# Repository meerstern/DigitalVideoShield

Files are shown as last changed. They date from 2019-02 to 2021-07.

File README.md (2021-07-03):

# DigitalVideoShield
Digital Video Shield for Arduino. The shield enables Arduino to connect HDMI/DVI displays.

## 概要 
  * SPIからDVI映像出力(HDMIコネクタ)を行うArduinoシールドです。  
  * FTDI製ビデオエンジンBT816とDVIトランスミッタTFP410/SiI164を搭載しています。
  
## 特徴 
  * Arduinoから任意の文字列や図形、画像をDVI/HDMIディスプレイに描画することができます。  
  * 1MBのバッファRAMを搭載しているため、滑らかに表示の切り替えが可能です。
  * バッファIC搭載のSPI通信ポートは5V耐圧のため、ArduinoUNOにも対応しています。  
  * 電源はArduinoピンから5Vおよび3.3Vを使用します。  
  * 最大解像度は800x600です。  
  * PCLK最大60MHz、24bitフルカラー(RGB888)に対応しています。  
  * 128MbitのNOR Flash W25Q128を搭載しており、フォントや画像といった任意のデータを保存可能です。  
  * microSDスロットを搭載しています。  
  * BT816のGPIOやタッチパネルポート等のIOは基板上のテストポイントからアクセス可能です。  

## ピン配列

| Port | Arduino | 
|:---|:---|
| BT816 CS | D7pin |
| BT816 SCK | D13pin |
| BT816 MOSI  | D11pin |
| BT816 MISO | D12pin |
| BT816 PD  | D3pin |
| BT816 INT | D4pin |
| microSD CS | D5pin |
| microSD SCK | D13pin |※BT816と共通
| microSD MOSI | D11pin |※BT816と共通
| microSD MISO | D12pin |※BT816と共通

※SPIはmicroSDとBT816で共通  
※上記の信号ポートは5V耐圧  

## 表示例
　サンプルデモコード(ビデオエンジンBT816の内蔵アニメーション)を800x480のディスプレイに表示した例  
 
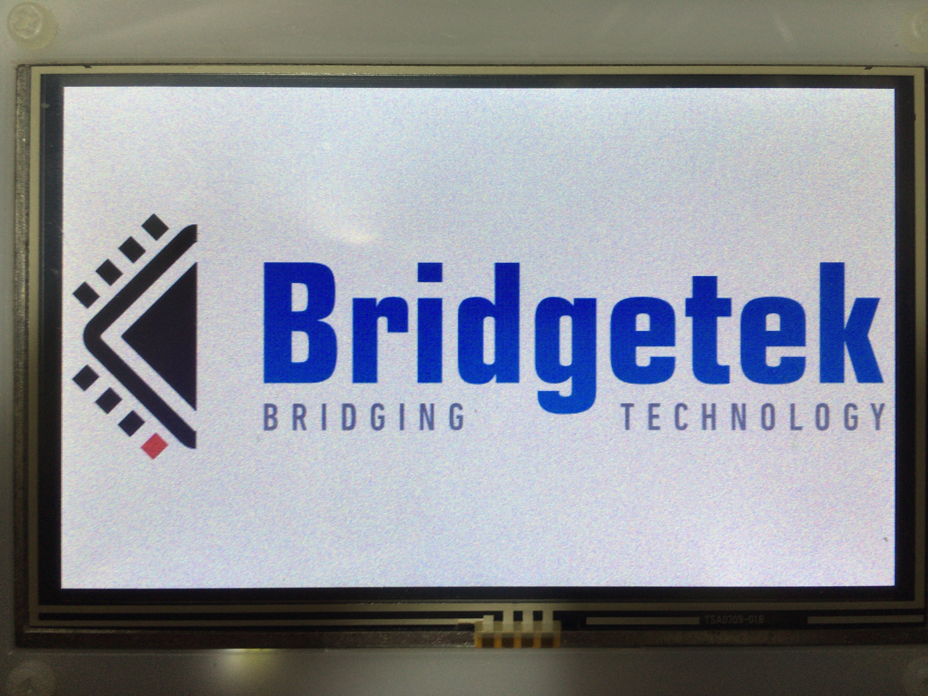
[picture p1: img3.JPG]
 

　サンプルデモコード(ビデオエンジンBT816の内蔵アニメーション)を800x480出力でHDディスプレイに表示した例  
 
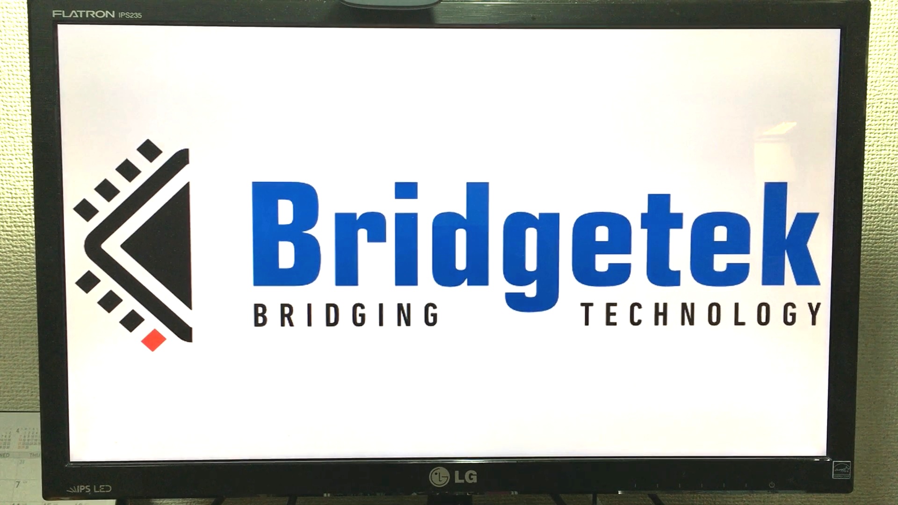
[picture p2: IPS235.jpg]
 
 
 Co-Processorエンジンによる内蔵Widgetsを800x480のディスプレイに表示した例  
 
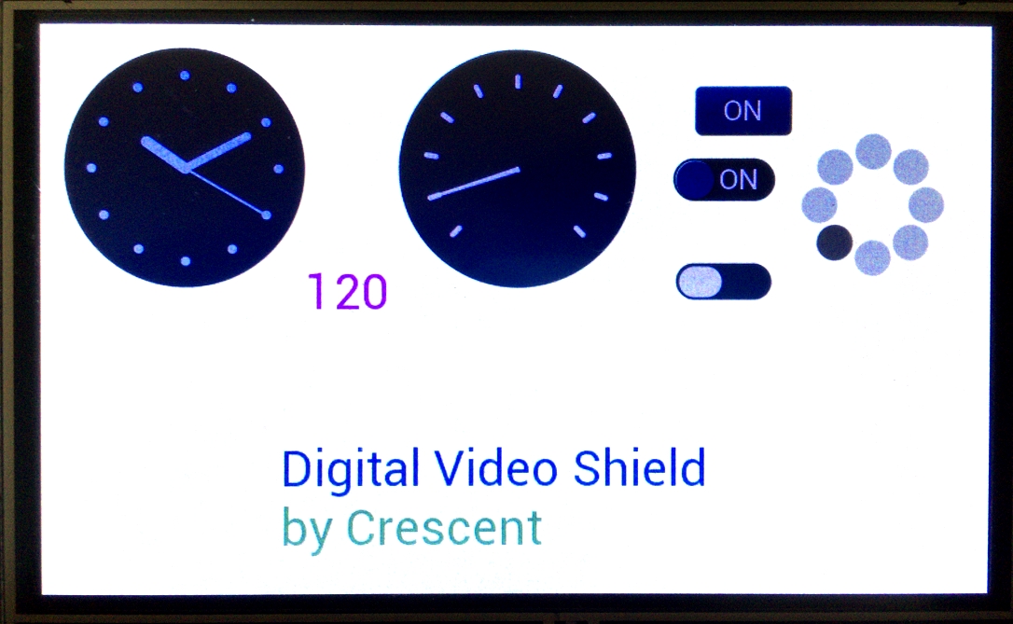
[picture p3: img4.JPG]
 
 ※内蔵Widgetsはテキスト、ボタン、時計、プログレスバー、スライダー、トグルボタンなどが内蔵されています。  
   
   数行のコードの記述で任意の表示をすることができます。     
   ボタン、スライダー等の入力イベントを使用する場合は別途、抵抗膜方式のパネルと配線が必要です。  
   
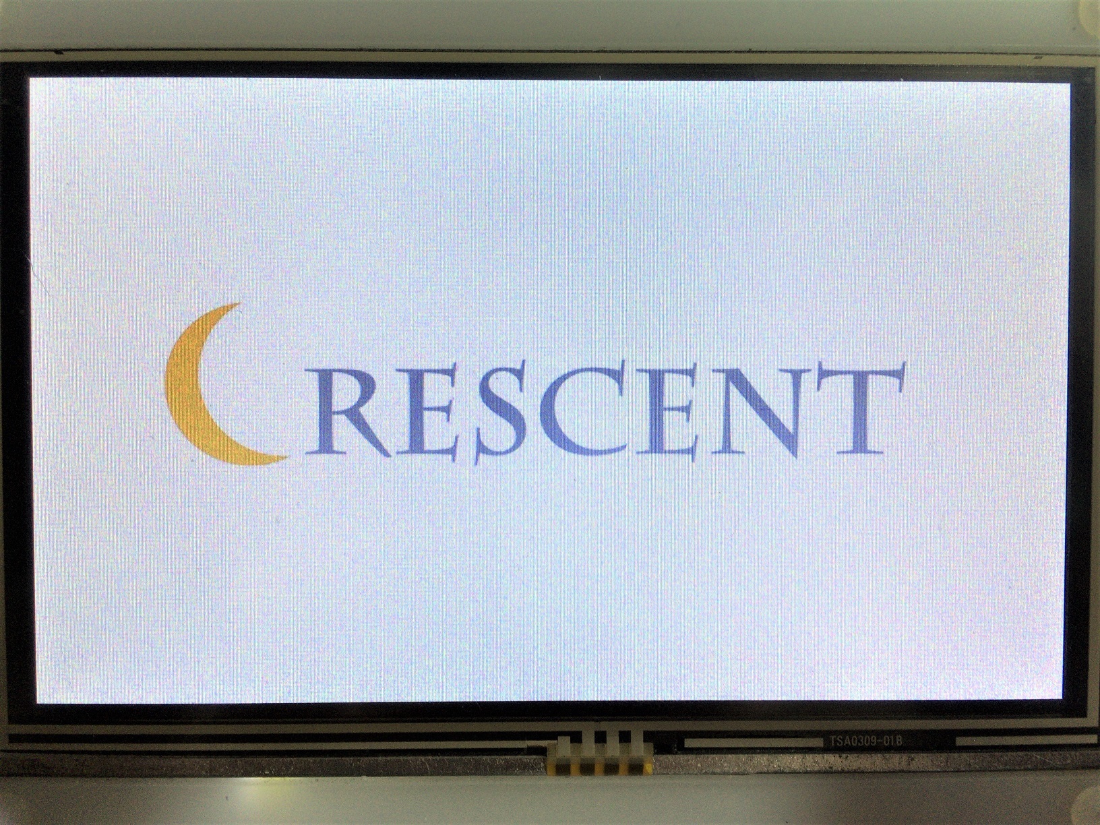
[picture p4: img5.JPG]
 
 ※SDカードから800x480ピクセルサイズのJPG/PNGをBT816のRAMに読み込ませて800x480のディスプレイに表示した例  

## 注意点
  * Arduinoピンヘッダは別売です。    
  * 映像出力コネクタはHDMIコネクタですが、出力はDVI出力となります。  
  * HDCP機能、HDMIコネクタを介した音声出力、ハイビジョン出力には対応していません。  
  * 全てのHDMI/DVI端子を有するディスプレイでの表示は保証できません。  
  * パソコン用ディスプレイのHDMIコネクタから表示できる場合がありますが、テレビやテレビ用ディスプレイはハイビジョン専用のため、表示できません。   
  * パソコン用ディスプレイの場合は低解像度入力で自動的に拡大表示されますが、ディスプレイによって正しく表示されない場合があります。  
  
機能詳細については[BT816][1]を参照ください。  

## 販売サイト
  * [家電のケンちゃん][2]、 [スイッチサイエンス][3]で販売しております。

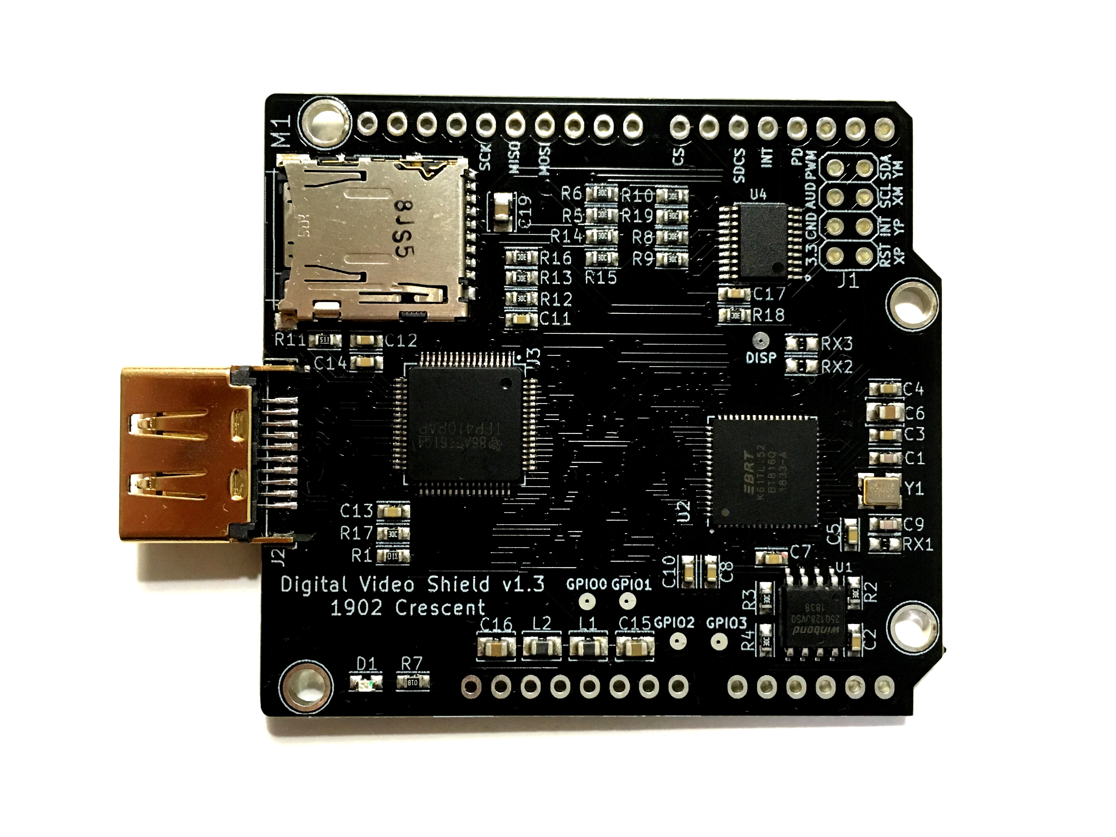
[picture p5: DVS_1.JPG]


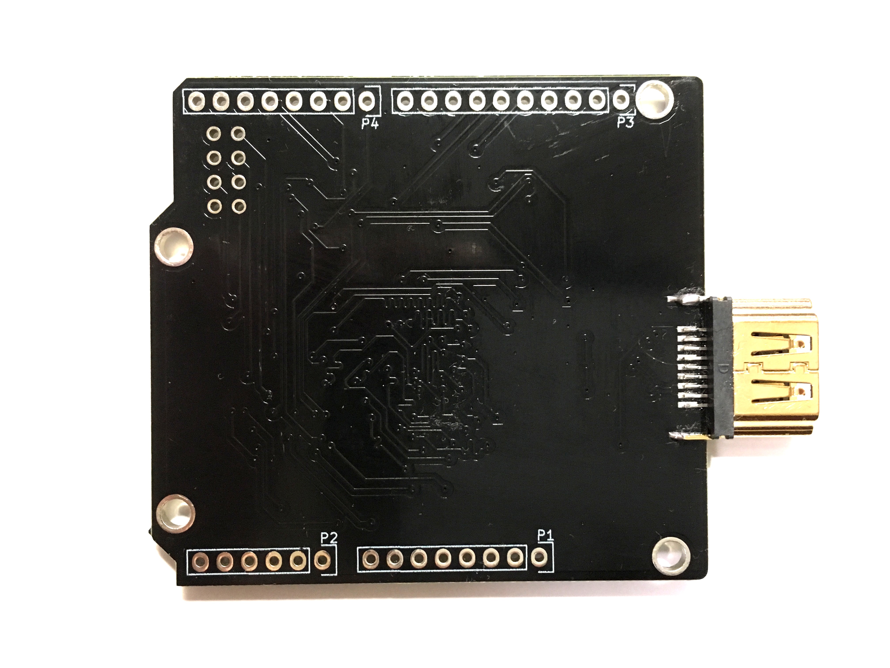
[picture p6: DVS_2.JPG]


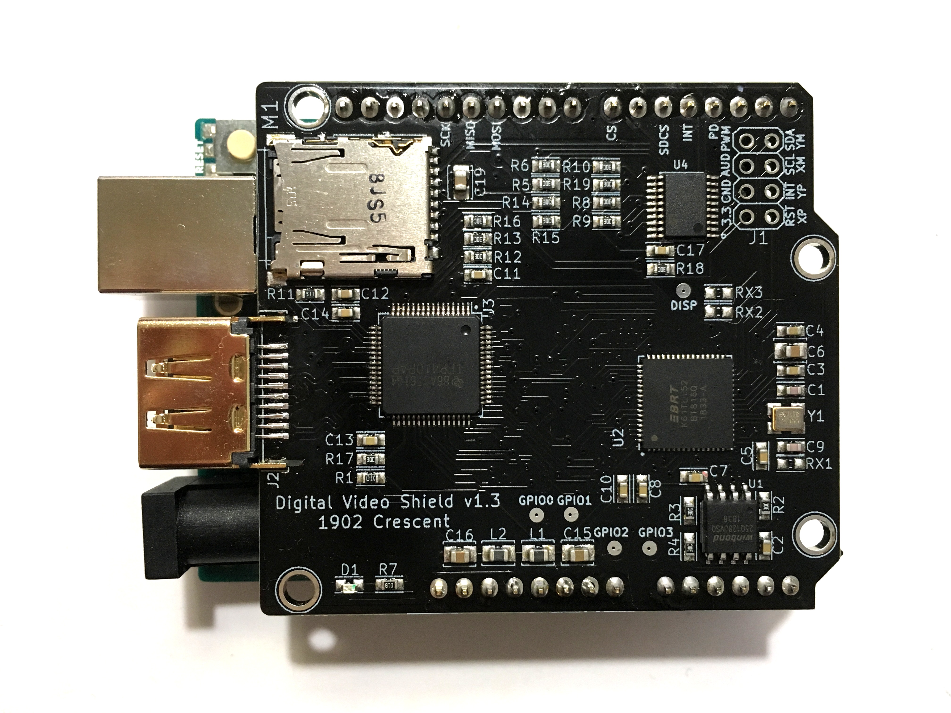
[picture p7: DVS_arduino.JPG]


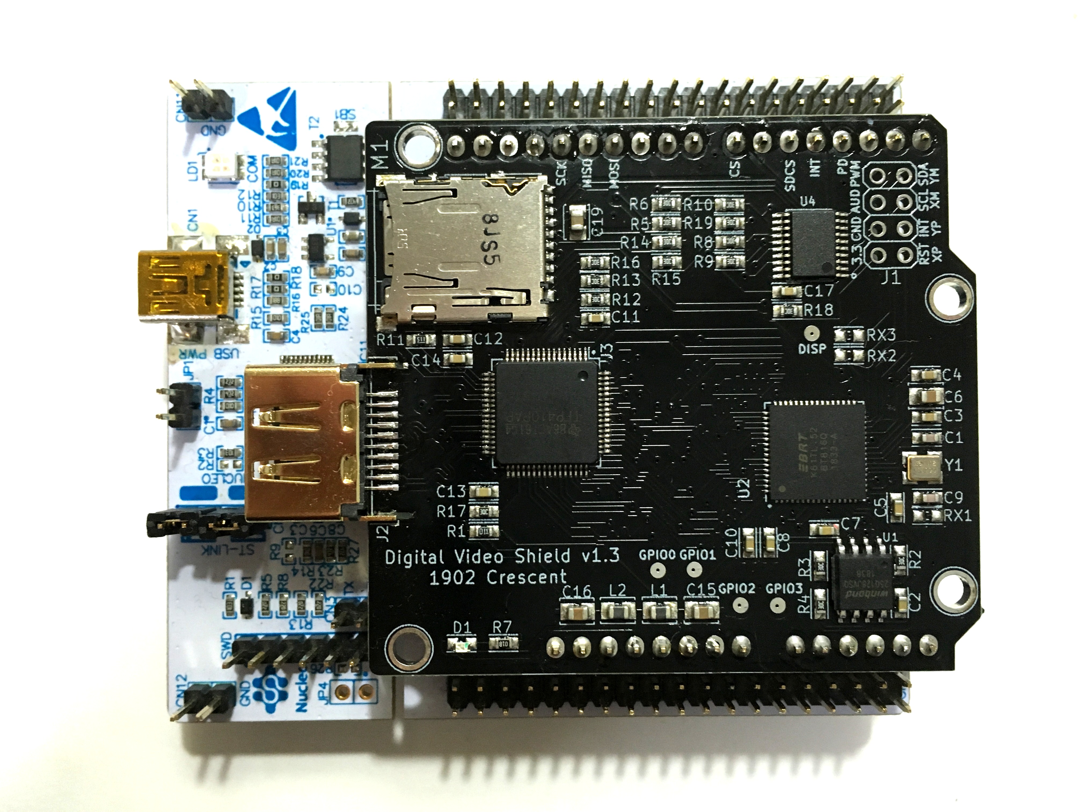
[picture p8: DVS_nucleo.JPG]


[1]: https://www.ftdichip.com/Products/ICs/BT815_6.html "*1"

[2]: https://www.kadenken.com/shopdetail/000000000884/ct150/page1/order/ "*2"

[3]: https://www.switch-science.com/catalog/5516/ "*3"

MIT Lisense

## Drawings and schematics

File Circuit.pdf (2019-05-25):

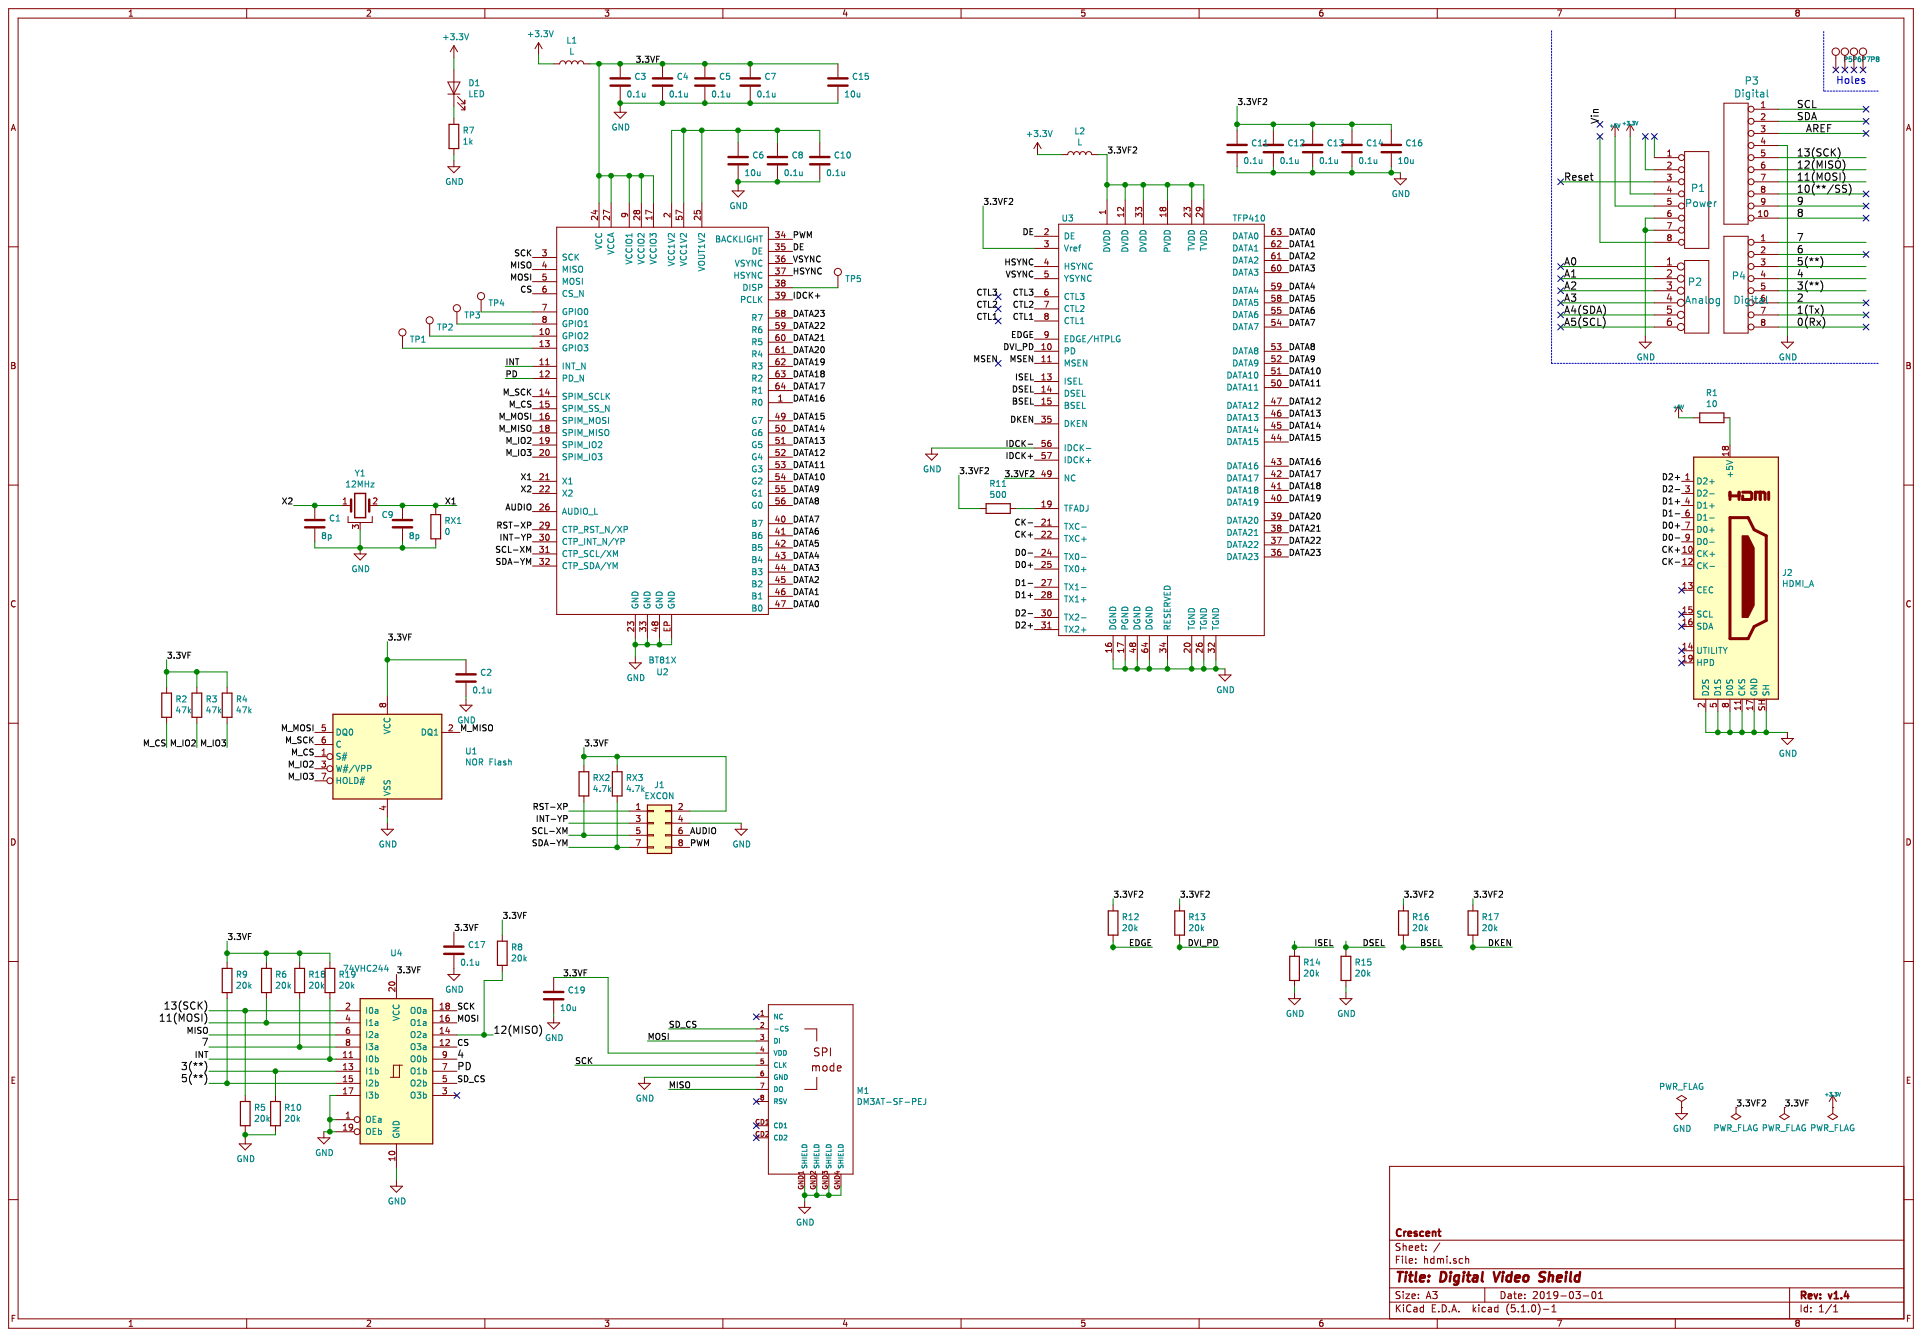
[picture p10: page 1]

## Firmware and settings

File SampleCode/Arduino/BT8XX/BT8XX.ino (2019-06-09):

/* * * * * * * * * * * * * * * * * * * * * * * * * *
 * FTDI EVE Firmware for BT81X                     *
 * Copyright (c) 2019                              *
 * K.Watanabe,Crescent                             *
 * Released under the MIT license                  *
 * http://opensource.org/licenses/mit-license.php  *
 * 19/02/16 v1.0 Initial Release                   *
 * 19/02/27 v1.1 Fix initialization stability      *
 * 19/04/28 v1.2 Add Co-Processor command          *
 * * * * * * * * * * * * * * * * * * * * * * * * * */

#include <Arduino.h>    
#include <SPI.h>       

#include "BT81X.h"

#ifdef ENABLE_SD
  #include <SD.h>
   File sdfile;
#endif

FILE serial_stdout;

void setup() 
{
    unsigned int cnt;
	
    Serial.begin(9600);
    fdev_setup_stream(&serial_stdout, serial_putchar, NULL, _FDEV_SETUP_WRITE);
    stdout = &serial_stdout;
             
    SPI.begin();          					// Initialize SPI
	  Serial.println("Initialize Start!! \r\n");
    SPI.setBitOrder(MSBFIRST);      		// Send data most significant bit first
    SPI.setDataMode(SPI_MODE0);     		// Clock idle zero, clock data into BT81X on rising edge
    SPI.setClockDivider(SPI_CLOCK_DIV4);    // Set rate at 4MHz (16MHz OSC / 4)

    pinMode(irqPin, INPUT_PULLUP);   		// BT81X interrupt output (not used in this example)
    pinMode(pwrPin, OUTPUT);     			// BT81X Power Down (reset) input
    pinMode(csPin, OUTPUT);      			// BT81X SPI bus CS# input
    pinMode(sdcsPin, OUTPUT);      			// BT81X SPI bus CS# input

	
    digitalWrite(sdcsPin, HIGH);   			// Set CS# high to start - SPI inactive
	  digitalWrite(csPin, HIGH);   			// Set CS# high to start - SPI inactive
    digitalWrite(pwrPin, HIGH);    			// Set PD# high to start
    delay(80);          					// Wait a few MS before waking the BT81X
    digitalWrite(pwrPin, LOW);    			// Set PD# high to start
    delay(80);  
    digitalWrite(pwrPin, HIGH);    			// Set PD# high to start
	  delay(80); 

	
  	EveWriteCmd(CLKEXT);    
  	EveWriteCmd(CLK36M);      
   	EveWriteCmd(ACTIVE);     
  	delay(300); 

#ifdef ENABLE_SD
	if (!SD.begin(sdcsPin)) 
	{
		Serial.println("SD initialization failed!\n");
	}    
#endif
	
  	while(CHIP_ID_RESET!=EveReadData8(REG_ID)){
  		cnt++;
  		if(cnt>100){
        Serial.print("EVE NOT Found!! :");
        Serial.println(EveReadData8(REG_ID));
  			delay(100);
  			break;
  		}
  	} 
    if(cnt<100)Serial.println("EVE Found!!");

      
  
  	cnt=0;
  	while(0x0!=EveReadData16(REG_CPURESET)){
  		cnt++;
      delay(1);
  		if(cnt>100){
  			Serial.print("EVE NOT Active!! :");
  			Serial.println(EveReadData16(REG_CPURESET));
  			delay(200);
  		}
  	}
	  if(cnt<100)Serial.println("EVE Active!!");

    EveWriteData32(REG_FREQUENCY,0x3938700);   // Set CPU Frequency
    
  	// Set Resolution
  	EveWriteData16(REG_HCYCLE,	USR_HCYCLE);
  	EveWriteData16(REG_HOFFSET,	USR_HOFFSET);
  	EveWriteData16(REG_HSYNC0,	USR_HSYNC0);
  	EveWriteData16(REG_HSYNC1,	USR_HSYNC1);
  	EveWriteData16(REG_VCYCLE,	USR_VCYCLE);
  	EveWriteData16(REG_VOFFSET,	USR_VOFFSET);
  	EveWriteData16(REG_VSYNC0,	USR_VSYNC0);
  	EveWriteData16(REG_VSYNC1,	USR_VSYNC1);
  	EveWriteData8(REG_SWIZZLE,	USR_SWIZZLE);
  	EveWriteData8(REG_PCLK_POL,	USR_PCLK_POL);
  	EveWriteData16(REG_HSIZE,		USR_HSIZE);
  	EveWriteData16(REG_VSIZE,		USR_VSIZE);
  	EveWriteData8(REG_CSPREAD,	USR_CSPREAD);
  	EveWriteData8(REG_DITHER,		USR_DITHER);

    EveWriteData16(REG_GPIOX_DIR, 0xFFFF);
    EveWriteData16(REG_GPIOX, 0xFFFF);
  	
  	//Clear Dispaly
    EveWriteData32BufInc(RAM_DL,  CLEAR_COLOR_RGB(255,255,255));
    EveWriteData32BufInc(RAM_DL,  CLEAR(1,1,1));
    EveWriteData32BufInc(RAM_DL,  DISPLAY());
    EveWriteData32BufWrite();

    //Display swap
    EveWriteData8(REG_DLSWAP, DLSWAP_FRAME);


    //LCD visible
    EveWriteData8(REG_PCLK, USR_PCLK);
    delay(300);
  
    Serial.println("Hello");
}


void loop() 
{

  
//  EveDemo3();
//  while(1);  
  EveDemo();
//  //EveRecoverCoProcessor();
//  EveDemo2();  
//  EveDemo3();  
  //EveRecoverCoProcessor();
	

}


void EveWriteCmd(unsigned char ftCommand)
{
  digitalWrite(csPin, LOW);   
  SPI.transfer(ftCommand);     
  SPI.transfer(0x00);     
  SPI.transfer(0x00); 
  digitalWrite(csPin, HIGH);
}

unsigned char EveReadData8(unsigned long ftAddress)
{
  unsigned char ftData8 = ZERO;
  digitalWrite(csPin, LOW); 
  SPI.transfer((char)(ftAddress >> 16) | MEM_READ); 
  SPI.transfer((char)(ftAddress >> 8)); 
  SPI.transfer((char)(ftAddress)); 
  SPI.transfer(ZERO);      
  ftData8 = SPI.transfer(ZERO); 
  digitalWrite(csPin, HIGH); 
  return ftData8;     
}

unsigned int EveReadData16(unsigned long ftAddress)
{
  unsigned int ftData16;
  digitalWrite(csPin, LOW);
  SPI.transfer((char)(ftAddress >> 16) | MEM_READ);
  SPI.transfer((char)(ftAddress >> 8)); 
  SPI.transfer((char)(ftAddress));
  SPI.transfer(ZERO);      
  ftData16 = (SPI.transfer(ZERO));  
  ftData16 = (SPI.transfer(ZERO) << 8) | ftData16; 
  digitalWrite(csPin, HIGH);
  return ftData16;
}

unsigned long EveReadData32(unsigned long ftAddress)
{
  unsigned long ftData32;
  unsigned long res;
  digitalWrite(csPin, LOW);
  SPI.transfer((char)(ftAddress >> 16) | MEM_READ);
  SPI.transfer((char)(ftAddress >> 8));
  SPI.transfer((char)(ftAddress));
  SPI.transfer(ZERO);

  res = SPI.transfer(ZERO);
  ftData32 = ( res << 0); 
  res = SPI.transfer(ZERO);
  ftData32 = ( res << 8) | ftData32;
  res = SPI.transfer(ZERO);
  ftData32 = ( res << 16) | ftData32;
  res = SPI.transfer(ZERO);
  ftData32 = ( res << 24) | ftData32;

  digitalWrite(csPin, HIGH);
  return ftData32;
}

void EveWriteData8(unsigned long ftAddress, unsigned char ftData8)
{
  digitalWrite(csPin, LOW);
  SPI.transfer((char)(ftAddress >> 16) | MEM_WRITE);
  SPI.transfer((char)(ftAddress >> 8));
  SPI.transfer((char)(ftAddress));
  SPI.transfer(ftData8);  
  digitalWrite(csPin, HIGH);
}

void EveWriteData16(unsigned long ftAddress, unsigned int ftData16)
{

  digitalWrite(csPin, LOW);
  SPI.transfer((char)(ftAddress >> 16) | MEM_WRITE);
  SPI.transfer((char)(ftAddress >> 8));
  SPI.transfer((char)(ftAddress));
  SPI.transfer((char)(ftData16));
  SPI.transfer((char)(ftData16 >> 8));
  digitalWrite(csPin, HIGH);
}

void EveWriteData32(unsigned long ftAddress, unsigned long ftData32)
{
  digitalWrite(csPin, LOW);
  SPI.transfer((char)(ftAddress >> 16) | MEM_WRITE);
  SPI.transfer((char)(ftAddress >> 8));
  SPI.transfer((char)(ftAddress));
  SPI.transfer((char)(ftData32)); 
  SPI.transfer((char)(ftData32 >> 8));
  SPI.transfer((char)(ftData32 >> 16));
  SPI.transfer((char)(ftData32 >> 24));
  digitalWrite(csPin, HIGH); 
}

void EveWriteData32BufInc(unsigned long ftAddress, unsigned long ftData32)
{
  ftAddress=ftAddress+buf_size;
  digitalWrite(csPin, LOW);    
  SPI.transfer((char)(ftAddress >> 16) | MEM_WRITE);
  SPI.transfer((char)(ftAddress >> 8));
  SPI.transfer((char)(ftAddress));    
  SPI.transfer((char)(ftData32));  
  SPI.transfer((char)(ftData32 >> 8));
  SPI.transfer((char)(ftData32 >> 16));
  SPI.transfer((char)(ftData32 >> 24));  
  digitalWrite(csPin, HIGH);   
  buf_size=buf_size+4;
}

void EveReadMemory (uint32_t addr, uint8_t *buffer, uint32_t len){

  uint8_t wdata[4];

  wdata[0] = addr >> 16;
  wdata[1] = (addr & 0xFF00) >> 8;
  wdata[2] = addr & 0xFF;
  wdata[3] = 0;

  digitalWrite(csPin, LOW);  
  for(int i=0; i<3;i++){
     SPI.transfer(wdata[i]);
  }
  for(int i=0; i<len;i++){
     *(buffer+i)=SPI.transfer(ZERO);
  }
  digitalWrite(csPin, HIGH);
}

void EveLoadJpgFile(char *filename, uint32_t addr, uint32_t width, uint32_t hight)
{

  uint32_t  filesize=0;
  uint32_t  filesectors=0;
  uint32_t  sectorsspace=0;

#ifdef ENABLE_SD
  printf("Read SD & RAM Write Start\n\r");
  
  sdfile = SD.open(filename, FILE_READ);
  if(sdfile){
    printf("SD File Open Success\n\r");
  }
  else{
    printf("SD File Open ERR\n\r");
    return;
  }
   
  
  filesize = sdfile.size();
  filesectors = filesize/0x1000;

  if(filesize % 0x1000)   filesectors++;
  sectorsspace= ( 0x100000 - (addr - RAM_G)) / 0x1000;


  if ( filesectors > sectorsspace ){
    printf("Data size is over!\n\r");
    return;
  }

  printf("FileName:\"%s\" Size:%ld \r\n", filename,filesize);


  uint16_t m=0;
  EveWaitCmdFifoEmpty();
  EveSendCmd(CMD_LOADIMAGE);
  EveSendCmd(addr);
  EveSendCmd(0);//Options

  for(uint32_t i=0; i < (filesize/4 + 1) ; i++){

    uint32_t readbuf[4];

    uint32_t dat=0;

    readbuf[0]=(uint32_t)sdfile.read();
    readbuf[1]=(uint32_t)sdfile.read();
    readbuf[2]=(uint32_t)sdfile.read();
    readbuf[3]=(uint32_t)sdfile.read();

    dat =  (uint32_t)(readbuf[0]<<0)
        +(uint32_t)(readbuf[1]<<8)
        +(uint32_t)(readbuf[2]<<16)
        +(uint32_t)(readbuf[3]<<24);
    EveSendCmd(dat);
    m++;
  }

  printf("Read SD & RAM Write End\n\r");

  sdfile.close();

#endif

  EveWaitCmdFifoEmpty();
  EveSendCmd(CMD_DLSTART);
  EveSendCmd(CLEAR(1, 1, 1));
  EveCmdSetBitmap(RAM_G, RGB565, width, hight);
  EveSendCmd(BEGIN(BITMAPS));

//  EveCmdLoadIdentify();
//  EveCmdRotateAround(400,240, 180, 0.5);//Scale and Angle
//  EveCmdSetMatrix();

  EveSendCmd(VERTEX2II(0, 0, 0, 0));//Position
  EveSendCmd(END());
  EveSendCmd(DISPLAY());
  EveWriteData8(REG_DLSWAP, DLSWAP_FRAME);
  EveWaitCmdFifoEmpty();

}

void usrdelay(uint16_t t){
  
  uint32_t wait;
  wait = millis() + t;
  while(millis() < wait);
}

int serial_putchar(char c, FILE* f) {
    if (c == '\n') serial_putchar('\r', f);
    return Serial.write(c) == 1? 0 : 1;
}

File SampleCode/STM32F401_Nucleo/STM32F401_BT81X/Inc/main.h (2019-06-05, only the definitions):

#define B1_Pin GPIO_PIN_13
#define B1_GPIO_Port GPIOC
#define USART_TX_Pin GPIO_PIN_2
#define USART_TX_GPIO_Port GPIOA
#define USART_RX_Pin GPIO_PIN_3
#define USART_RX_GPIO_Port GPIOA
#define CS_Pin GPIO_PIN_8
#define CS_GPIO_Port GPIOA
#define TMS_Pin GPIO_PIN_13
#define TMS_GPIO_Port GPIOA
#define TCK_Pin GPIO_PIN_14
#define TCK_GPIO_Port GPIOA
#define PD_Pin GPIO_PIN_3
#define PD_GPIO_Port GPIOB
#define SDCS_Pin GPIO_PIN_4
#define SDCS_GPIO_Port GPIOB
#define INT_Pin GPIO_PIN_5
#define INT_GPIO_Port GPIOB

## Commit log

2019-02-24 Add Arduino Sample Code
2019-02-24 Add Nucleo Sample with SW4STM32
2019-04-13 Fix miscode and add logo
    [BT8XX.ino]
2019-06-07 Add JPG load sample
2021-07-03 Add gerber files
    [hdmi-B_Cu.gbl, hdmi-B_Mask.gbs, hdmi-B_Paste.gbp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]

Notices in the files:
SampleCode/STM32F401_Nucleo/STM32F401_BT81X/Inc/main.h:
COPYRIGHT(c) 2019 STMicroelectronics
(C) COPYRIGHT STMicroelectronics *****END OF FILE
